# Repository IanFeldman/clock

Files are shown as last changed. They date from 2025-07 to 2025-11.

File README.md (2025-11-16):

# Precision Clock USB Hub with Thermal and Power Sensing

<div align="center">
  PCB Render
</div>

## Features
- Time accurate to the second with ±5ppm drift
- Board temperature monitoring within ±0.5°C
- Dual USB power output up to a combined 1.5A
- Independent USB current/voltage measureement
- On board USB-Serial converter for easy programming/syncing
- Analog display brightness

## Build Deps
- lpc21isp (serial flasher)
- arm-none-eabi-gcc (cortex m compiler)

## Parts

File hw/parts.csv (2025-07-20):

Identifier | Value | Digikey Part Number
U1 |  | 568-10437-5-ND
U2 |  | 768-1135-1-ND
VR1 |  | LM3940IMP-3.3/NOPBCT-ND
S1, S2 |  | 2223-SLW-1678105-6A-N-D-ND
Y1 |  | 535-9887-1-ND
Y2 |  | 50-ECX-.327-CDX-1293CT-ND
U3, U4, U5, U6, U7, U8 |  | 296-14857-1-ND
U9 |  | MCP7940MT-I/SNCT-ND
R12 |  | 2223-PT01-B120D-B102-ND
U13 |  | MCP9808T-E/MSCT-ND
U15, U16 |  | 296-23978-1-ND
U14 |  | AP2192ASG-13DICT-ND
J1, J2, J3 |  | ED2989-ND
SW1, SW2, SW3 |  | EG5353CT-ND
C1, C2 | 16p | 311-4228-1-ND
C10, C6, C7, C13 | 1u | 1276-1029-1-ND
C11, C12 | 47p | 311-1107-1-ND
C3, C4 | 18p | 311-1102-1-ND
C5, C8, C9 | 100u | 490-GRM21BR60G107ME11KCT-ND
D1, D2, D3, D4 |  | 475-LSR976-NR-1CT-ND
R1, R10, R14, R19, R4, R5, R6, R7, R8, R9 | 10k | RR12P10.0KDCT-ND
R11 | 10 | 311-10.0CRCT-ND
R13 | 15k | A126341CT-ND
R15, R16 | 2m | RHM.002AJCT-ND
R17, R18, R20 | 0 | P0.0ACT-ND
R2, R3 | 27 | 311-27.0CRCT-ND
R21 | 15 | RMCF0805FT15R0CT-ND

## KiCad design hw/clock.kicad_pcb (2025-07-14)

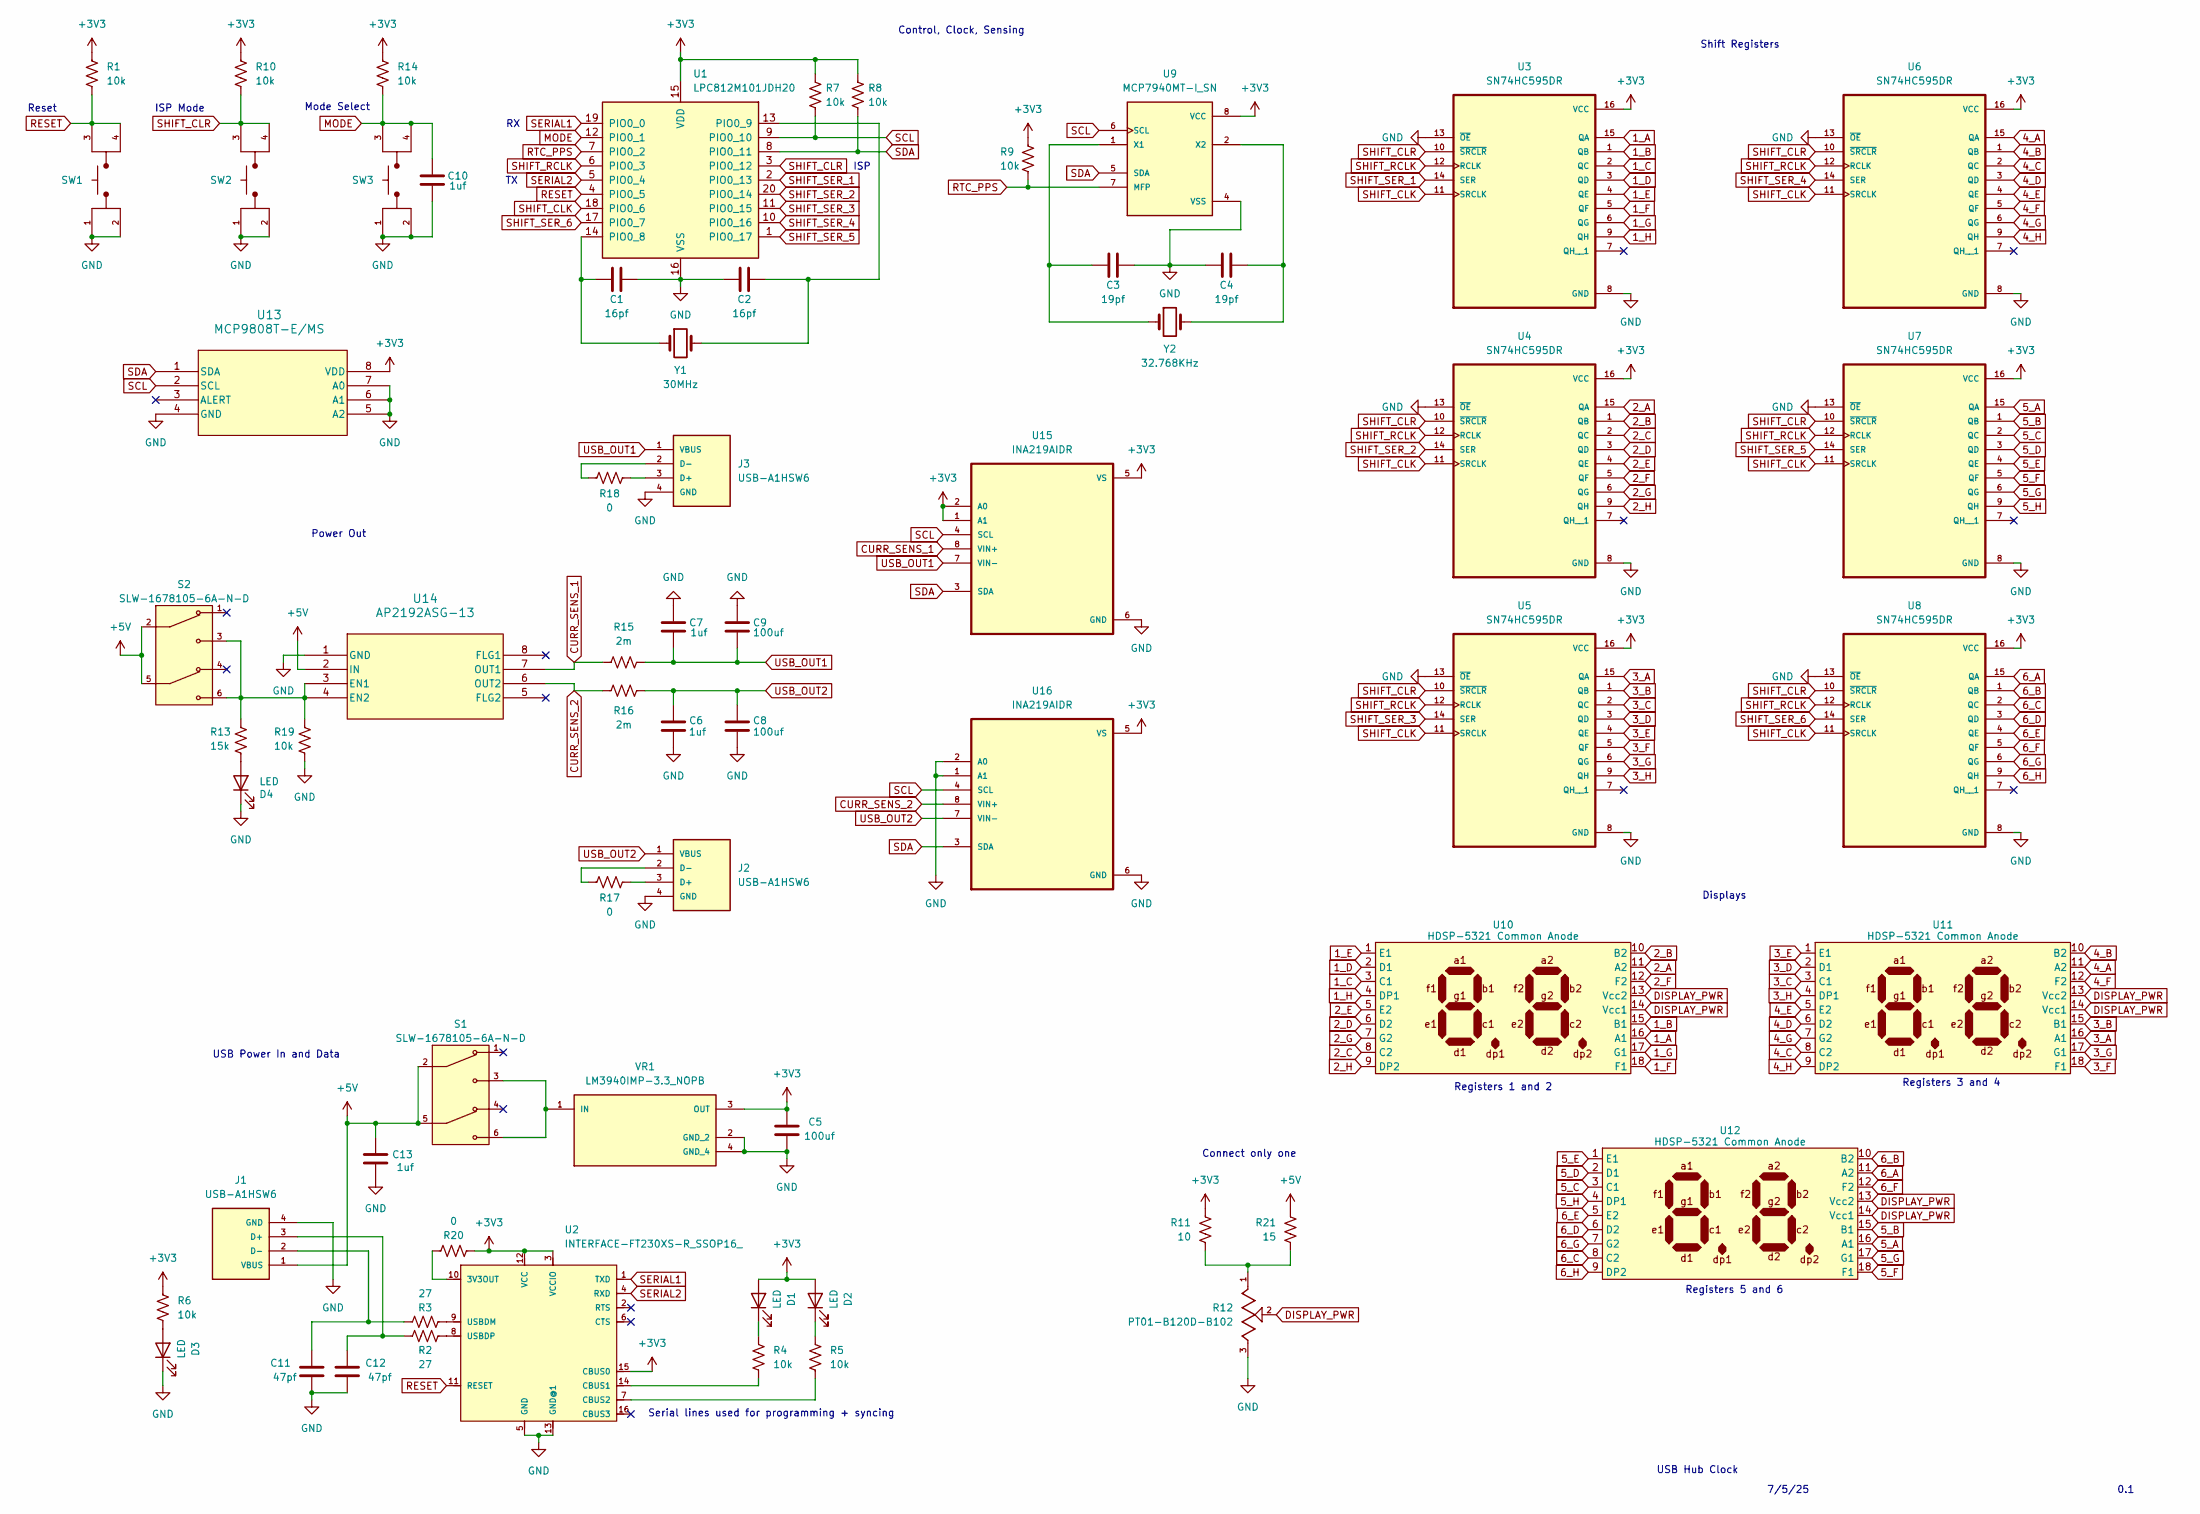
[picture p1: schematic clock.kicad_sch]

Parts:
C1, C2: 16pf; C_0805_2012Metric
C3, C4: 19pf; C_0805_2012Metric
C5, C8, C9: 100uf; C_0805_2012Metric
C6, C7, C10, C13: 1uf; C_0805_2012Metric
C11, C12: 47pf; C_0805_2012Metric
D1, D2, D3, D4: LED; LED_0805_2012Metric
J1, J2, J3: USB-A1HSW6; OST_USB-A1HSW6; PARTREV A
R1, R4, R5, R6, R7, R8, R9, R10, R14, R19: 10k; R_0805_2012Metric
R2, R3: 27; R_0805_2012Metric
R11: 10; R_0805_2012Metric
R12: PT01-B120D-B102; TRIM_PT01-B120D-B102; PARTREV 1.0
R13: 15k; R_0805_2012Metric
R15, R16: 2m; R_0805_2012Metric
R17, R18, R20: 0; R_0805_2012Metric
R21: 15; R_0805_2012Metric
S1, S2: SLW-1678105-6A-N-D; SW_SLW-1678105-6A-N-D; PARTREV 1.01
SW1, SW2, SW3: TL3305AF260QG; SW_TL3305AF260QG; PARTREV C
U1: LPC812M101JDH20; TSSOP-20_4.4x6.5mm_P0.65mm
U2: INTERFACE-FT230XS-R_SSOP16_; SSOP16-0.635-5X4MM; MPN FT230XS-R
U3, U4, U5, U6, U7, U8: SN74HC595DR; SOIC127P600X175-16N
U9: MCP7940MT-I_SN; SOIC127P600X175-8N
U10, U11, U12: HDSP-5321 Common Anode; HDSP-R
U13: MCP9808T-E/MS; MCP9808T
U14: AP2192ASG-13; AP2192ASG_13
U15, U16: INA219AIDR
VR1: LM3940IMP-3.3_NOPB; VREG_LM3940IMP-3.3_NOPB; PARTREV G
Y1: 30MHz; XTAL_ABLS2-30.000MHZ-D4YF-T
Y2: 32.768KHz; XTAL_ECS-.327-12.5-34RR-TR

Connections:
1_A: U3.15 (QA), U10.16 (A1)
1_B: U3.1 (QB), U10.15 (B1)
1_C: U3.2 (QC), U10.3 (C1)
1_D: U3.3 (QD), U10.2 (D1)
1_E: U3.4 (QE), U10.1 (E1)
1_F: U3.5 (QF), U10.18 (F1)
1_G: U3.6 (QG), U10.17 (G1)
1_H: U3.9 (QH), U10.4 (DP1)
2_A: U4.15 (QA), U10.11 (A2)
2_B: U4.1 (QB), U10.10 (B2)
2_C: U4.2 (QC), U10.8 (C2)
2_D: U4.3 (QD), U10.6 (D2)
2_E: U4.4 (QE), U10.5 (E2)
2_F: U4.5 (QF), U10.12 (F2)
2_G: U4.6 (QG), U10.7 (G2)
2_H: U4.9 (QH), U10.9 (DP2)
3_A: U5.15 (QA), U11.16 (A1)
3_B: U5.1 (QB), U11.15 (B1)
3_C: U5.2 (QC), U11.3 (C1)
3_D: U5.3 (QD), U11.2 (D1)
3_E: U5.4 (QE), U11.1 (E1)
3_F: U5.5 (QF), U11.18 (F1)
3_G: U5.6 (QG), U11.17 (G1)
3_H: U5.9 (QH), U11.4 (DP1)
4_A: U6.15 (QA), U11.11 (A2)
4_B: U6.1 (QB), U11.10 (B2)
4_C: U6.2 (QC), U11.8 (C2)
4_D: U6.3 (QD), U11.6 (D2)
4_E: U6.4 (QE), U11.5 (E2)
4_F: U6.5 (QF), U11.12 (F2)
4_G: U6.6 (QG), U11.7 (G2)
4_H: U6.9 (QH), U11.9 (DP2)
5_A: U7.15 (QA), U12.16 (A1)
5_B: U7.1 (QB), U12.15 (B1)
5_C: U7.2 (QC), U12.3 (C1)
5_D: U7.3 (QD), U12.2 (D1)
5_E: U7.4 (QE), U12.1 (E1)
5_F: U7.5 (QF), U12.18 (F1)
5_G: U7.6 (QG), U12.17 (G1)
5_H: U7.9 (QH), U12.4 (DP1)
6_A: U8.15 (QA), U12.11 (A2)
6_B: U8.1 (QB), U12.10 (B2)
6_C: U8.2 (QC), U12.8 (C2)
6_D: U8.3 (QD), U12.6 (D2)
6_E: U8.4 (QE), U12.5 (E2)
6_F: U8.5 (QF), U12.12 (F2)
6_G: U8.6 (QG), U12.7 (G2)
6_H: U8.9 (QH), U12.9 (DP2)
+3V3: C5.2, D1.2 (A), D2.2 (A), R1.2, R6.2, R7.2, R8.2, R9.2, R10.2, R11.2, R14.2, R20.2, U1.15 (VDD), U2.3 (VCCIO), U2.12 (VCC), U2.15 (CBUS0), U3.16 (VCC), U4.16 (VCC), U5.16 (VCC), U6.16 (VCC), U7.16 (VCC), U8.16 (VCC), U9.8 (VCC), U13.8 (VDD), U15.1 (A1), U15.2 (A0), U15.5 (VS), U16.5 (VS), VR1.3 (OUT)
+5V: C13.2, J1.1 (VBUS), R21.2, S1.2, S1.5, S2.2, S2.5, U14.2 (IN)
CURR_SENS_1: R15.2, U14.7 (OUT1), U15.8 (VIN+)
CURR_SENS_2: R16.2, U14.6 (OUT2), U16.8 (VIN+)
DISPLAY_PWR: R12.2, U10.13 (Vcc2), U10.14 (Vcc1), U11.13 (Vcc2), U11.14 (Vcc1), U12.13 (Vcc2), U12.14 (Vcc1)
GND: C1.2, C2.1, C3.2, C4.1, C5.1, C6.1, C7.1, C8.1, C9.1, C10.2, C11.1, C12.1, C13.1, D3.1 (K), D4.1 (K), J1.4 (GND), J2.4 (GND), J3.4 (GND), R12.3, R19.1, SW1.1, SW1.2, SW2.1, SW2.2, SW3.1, SW3.2, U1.16 (VSS), U2.5 (GND), U2.13 (GND@1), U3.8 (GND), U3.13 (~OE), U4.8 (GND), U4.13 (~OE), U5.8 (GND), U5.13 (~OE), U6.8 (GND), U6.13 (~OE), U7.8 (GND), U7.13 (~OE), U8.8 (GND), U8.13 (~OE), U9.4 (VSS), U13.4 (GND), U13.5 (A2), U13.6 (A1), U13.7 (A0), U14.1 (GND), U15.6 (GND), U16.1 (A1), U16.2 (A0), U16.6 (GND), VR1.2 (GND_2), VR1.4 (GND_4)
MODE: C10.1, R14.1, SW3.3, SW3.4, U1.12 (PIO0_1)
unnamed: D1.1 (K), R4.2
unnamed: D2.1 (K), R5.2
unnamed: D3.2 (A), R6.1
unnamed: D4.2 (A), R13.1
unnamed: C12.2, J1.3 (D+), R2.1
unnamed: C11.2, J1.2 (D-), R3.2
unnamed: J2.3 (D+), R17.1
unnamed: J2.2 (D-), R17.2
unnamed: J3.3 (D+), R18.1
unnamed: J3.2 (D-), R18.2
unnamed: R11.1, R12.1, R21.1
unnamed: C1.1, U1.14 (PIO0_8), Y1.1
unnamed: C2.2, U1.13 (PIO0_9), Y1.2
unnamed: R20.1, U2.10 (3V3OUT)
unnamed: R4.1, U2.14 (CBUS1)
unnamed: R5.1, U2.7 (CBUS2)
unnamed: R3.1, U2.9 (USBDM)
unnamed: R2.2, U2.8 (USBDP)
unnamed: C3.1, U9.1 (X1), Y2.1
unnamed: C4.2, U9.2 (X2), Y2.2
unnamed: R13.2, R19.2, S2.3, S2.6, U14.3 (EN1), U14.4 (EN2)
unnamed: S1.3, S1.6, VR1.1 (IN)
RESET: R1.1, SW1.3, SW1.4, U1.4 (PIO0_5), U2.11 (RESET)
RTC_PPS: R9.1, U1.7 (PIO0_2), U9.7 (MFP)
SCL: R7.1, U1.9 (PIO0_10), U9.6 (SCL), U13.2 (SCL), U15.4 (SCL), U16.4 (SCL)
SDA: R8.1, U1.8 (PIO0_11), U9.5 (SDA), U13.1 (SDA), U15.3 (SDA), U16.3 (SDA)
SERIAL1: U1.19 (PIO0_0), U2.1 (TXD)
SERIAL2: U1.5 (PIO0_4), U2.4 (RXD)
SHIFT_CLK: U1.18 (PIO0_6), U3.11 (SRCLK), U4.11 (SRCLK), U5.11 (SRCLK), U6.11 (SRCLK), U7.11 (SRCLK), U8.11 (SRCLK)
SHIFT_CLR: R10.1, SW2.3, SW2.4, U1.3 (PIO0_12), U3.10 (~SRCLR), U4.10 (~SRCLR), U5.10 (~SRCLR), U6.10 (~SRCLR), U7.10 (~SRCLR), U8.10 (~SRCLR)
SHIFT_RCLK: U1.6 (PIO0_3), U3.12 (RCLK), U4.12 (RCLK), U5.12 (RCLK), U6.12 (RCLK), U7.12 (RCLK), U8.12 (RCLK)
SHIFT_SER_1: U1.2 (PIO0_13), U3.14 (SER)
SHIFT_SER_2: U1.20 (PIO0_14), U4.14 (SER)
SHIFT_SER_3: U1.11 (PIO0_15), U5.14 (SER)
SHIFT_SER_4: U1.10 (PIO0_16), U6.14 (SER)
SHIFT_SER_5: U1.1 (PIO0_17), U7.14 (SER)
SHIFT_SER_6: U1.17 (PIO0_7), U8.14 (SER)
USB_OUT1: C7.2, C9.2, J3.1 (VBUS), R15.1, U15.7 (VIN-)
USB_OUT2: C6.2, C8.2, J2.1 (VBUS), R16.1, U16.7 (VIN-)

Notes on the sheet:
Power Out
Registers 1 and 2
7/5/25
ISP Mode
Mode Select
USB Power In and Data
Reset
USB Hub Clock
Connect only one
Registers 3 and 4
Displays
ISP
Serial lines used for programming + syncing
0.1
Control, Clock, Sensing
Shift Registers
Registers 5 and 6

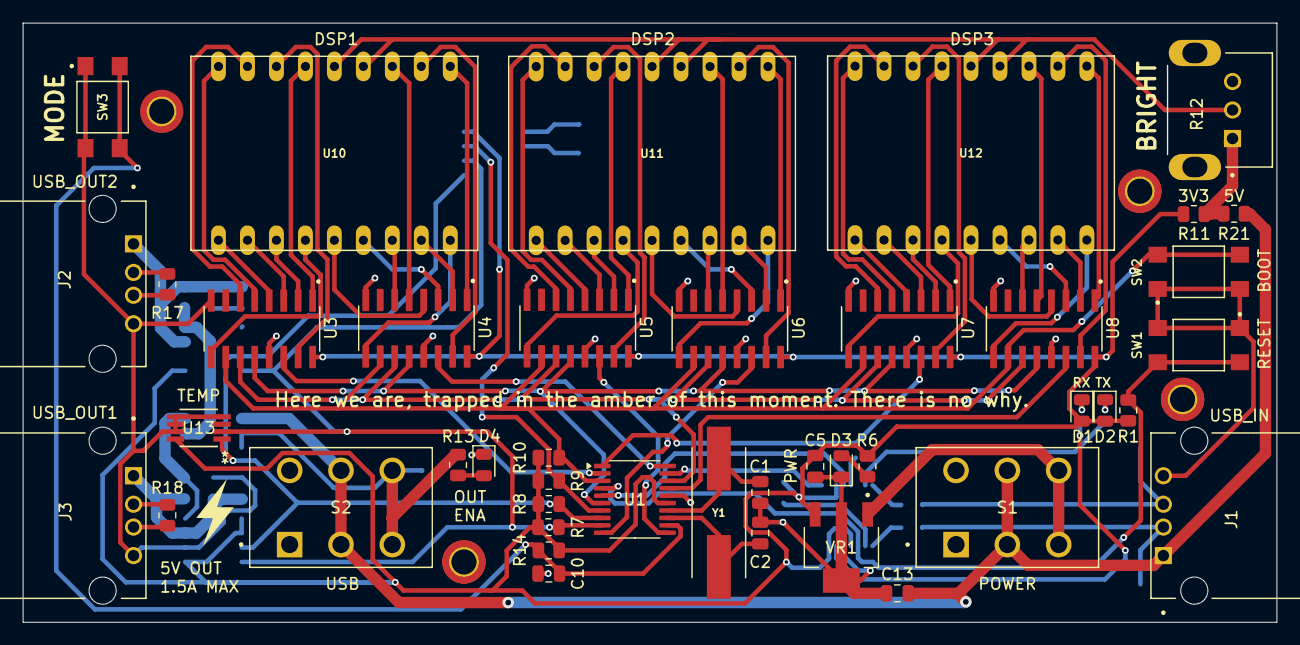
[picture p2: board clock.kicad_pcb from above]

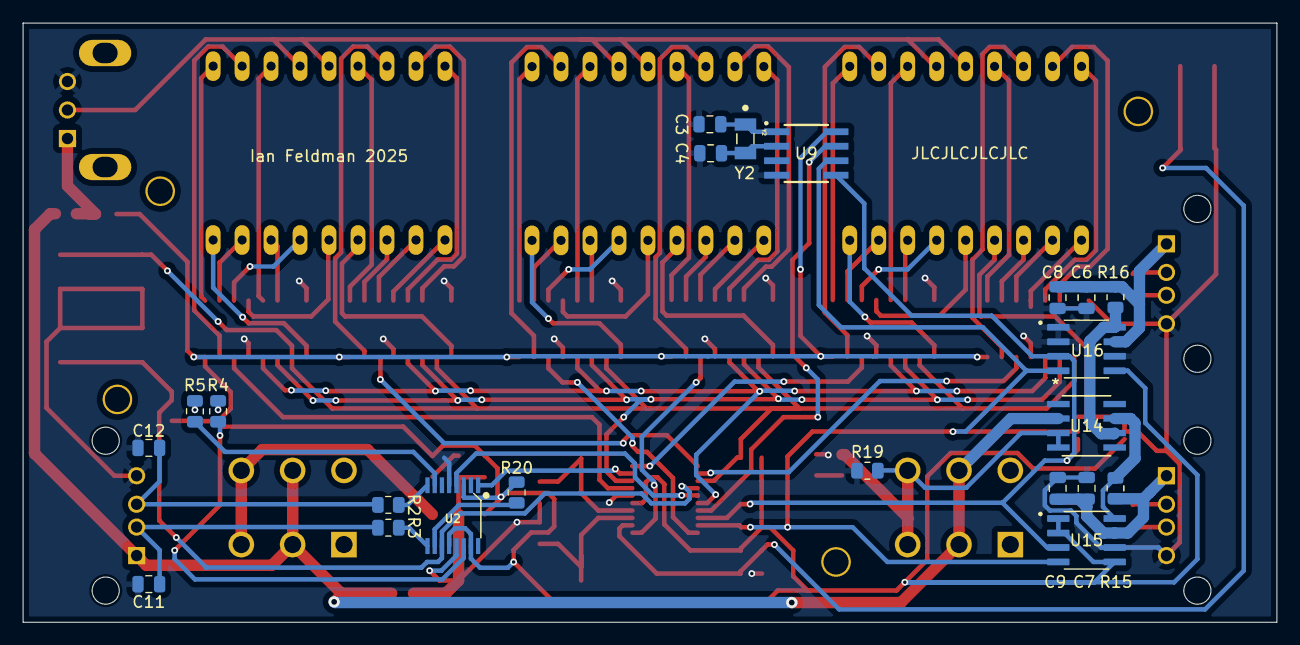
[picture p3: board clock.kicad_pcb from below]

Board: 2 copper layers, 109.9 x 52.5 mm, 65 parts (22 on the bottom side), 94 nets.

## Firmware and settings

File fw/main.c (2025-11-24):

#include "LPC8xx.h"
#include "display.h"
#include "i2c.h"
#include "uart.h"
#include "main.h"

static inline void increment_time(void);
static void gpio_int_initialize(void);
static int debounce(void);

/* isr variables */
volatile rtc_time_t time = { 0, 0, 0, 0, 0 };
volatile int pps_flag = 0;
volatile int mode_flag = 0;
volatile int rx_flag = 0;
volatile char rx_buffer[32];

int main(void)
{
    display_initialize();
    uart_initialize();
    i2c_initialize();

    /* reset terminal */
    uart_print_esc(CLEAR_SCREEN);
    uart_print_esc(HOME_CURSOR);

    /* initialize pin interrupts */
    gpio_int_initialize();

    /* initalize time */
    i2c_rtc_output_config();
    i2c_rtc_set_time(time);

    /* 0: off, 1: time, ... */
    int mode = 1;
    int update_display = 0;

    while (1)
    {
        /* check incoming message */
        if (rx_flag)
        {
            uart_handle_message((char *)rx_buffer, (rtc_time_t *)&time);
            i2c_rtc_set_time(time);
            update_display = 1;
            rx_flag = 0;
        }

        /* check mode */
        if (mode_flag && debounce())
        {
            mode++;
            if (mode >= MODE_COUNT)
            {
                mode = 0;
                display_clear();
            }
            else
            {
                update_display = 1;
            }
        }

        /* service 1hz pps */
        if (pps_flag || update_display)
        {
            switch(mode)
            {
                /* normal time display */
                case 1:
                    display_time((rtc_time_t *)&time);
                    break;

                /* temperature display */
                case 2:
                    tmp_temp_t temp_c = i2c_tmp_get_temp(DEG_C);
                    display_temp(&temp_c);
                    break;

                /* temperature display */
                case 3:
                    tmp_temp_t temp_f = i2c_tmp_get_temp(DEG_F);
                    display_temp(&temp_f);
                    break;

                /* off */
                default:
                    break;
            }
            pps_flag = 0;
            update_display = 0;
        }
    }

    return 1;
}


/* Enable external interrupts for gpio pins:
 *  - Rising edge PININT0 for PPS (PIO0_2)
 *  - Falling edge PININT1 for MODE (PIO0_1)
 */
static void gpio_int_initialize(void)
{
    /* disable SWDIO function (bit 3) so PIO0_2 can be used as GPIO */
    /* disable ACMP_I2 function (bit 1) so PIO0_1 can be used as GPIO */
    LPC_SWM->PINENABLE0 |= (1 << 3) | (1 << 1);
    /* set pins as inputs */
    LPC_GPIO_PORT->DIR0 &= ~((1 << PPS_PIN) | (1 << MODE_PIN));
    /* set external interrupts */
    LPC_SYSCON->PINTSEL[PPS_IRQ] = PPS_PIN;
    LPC_SYSCON->PINTSEL[MODE_IRQ] = MODE_PIN;
    /* set edge sensitive */
    LPC_PIN_INT->ISEL &= ~((1 << PPS_IRQ) | (1 << MODE_IRQ));
    /* PPS detect rising edge */
    LPC_PIN_INT->IENR |= (1 << PPS_IRQ);
    /* MODE detect falling edge */
    LPC_PIN_INT->IENF |= (1 << MODE_IRQ);
    /* clear any pending/leftover flags */
    LPC_PIN_INT->IST = 0xFF;
    /* enable interrupts */
    NVIC_EnableIRQ(PININT0_IRQn);
    NVIC_EnableIRQ(PININT1_IRQn);
}


/* Increment current time by one second */
static inline void increment_time(void)
{
    time.seconds_ones++;
    /* check seconds */
    if (time.seconds_ones > 9)
    {
        time.seconds_ones = 0;
        time.seconds_tens++;

        if (time.seconds_tens > 5)
        {
            time.seconds_tens = 0;
            time.minutes_ones++;
        }
    }

    /* check minutes */
    if (time.minutes_ones > 9)
    {
        time.minutes_ones = 0;
        time.minutes_tens++;

        if (time.minutes_tens > 5)
        {
            time.minutes_tens = 0;
            time.hours_ones++;
        }
    }

    /* check hours */
    if (time.hours_ones > 9)
    {
        time.hours_ones = 0;
        time.hours_tens++;
    }

    /* reset hours to 0 at 24 */
    if (time.hours_tens > 1 && time.hours_ones > 3)
    {
        time.hours_tens = 0;
        time.hours_ones = 0;
    }
}


/* Debounce MODE pin input. Return 1 if pressed, 0 otherwise */
static int debounce(void)
{
    static int counter = 0;

    counter++;
    /* timeout */
    if (counter > MODE_DEBOUNCE)
    {
        /* active low */
        int press = !(LPC_GPIO_PORT->B0[MODE_PIN]);
        counter = 0; 
        mode_flag = 0;
        return press;
    }
    return 0;
}


/* RTC PPS external interrrupt handler */
void PININT0_IRQHandler(void)
{
    /* check interrupt flag */
    if (LPC_PIN_INT->IST & (1 << PPS_IRQ))
    {
        pps_flag = 1;
        increment_time();
        LPC_PIN_INT->IST = (1 << PPS_IRQ);
    }
}


/* MODE pin external interrrupt handler */
void PININT1_IRQHandler(void)
{
    /* check interrupt flag and set mode flag */
    if (LPC_PIN_INT->IST & (1 << MODE_IRQ))
    {
        mode_flag = 1;
        LPC_PIN_INT->IST = (1 << MODE_IRQ);
    }
}


/* Serial interrupt handler */
void UART0_IRQHandler(void)
{
    static int rx_idx = 0;

    /* rx ready */
    if (LPC_USART0->INTSTAT & (1 << UART_RX_INT_RDY)) {
        /* get byte */
        char rx_byte = LPC_USART0->RXDATA;
        if (!rx_idx && (rx_byte != UART_RX_SYNC)) return;
        rx_buffer[rx_idx++] = rx_byte;

        /* reset index and set flag if we received full message */
        int full_msg_size = (sizeof(clk_set_msg_t) + sizeof(UART_RX_SYNC));
        if (rx_idx == full_msg_size) {
            rx_idx = 0;
            rx_flag = 1;
        }
    }
}

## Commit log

2025-06-09 Create hardware files
    [clock.kicad_pcb, clock.kicad_sch]
2025-06-09 Add USB
    [clock.kicad_sch]
2025-06-12 Add voltage reg and serial converter
    [clock.kicad_sch]
2025-06-12 Change mcu
    [clock.kicad_sch]
2025-06-17 Shift registers
    [clock.kicad_sch]
2025-06-20 Variable brightness, temperature sense
    [clock.kicad_sch]
2025-06-21 USB output
    [clock.kicad_sch]
2025-06-24 Assign footprints
    [clock.kicad_pcb, clock.kicad_sch]
2025-06-30 Minor schematic changes, routing
    [clock.kicad_pcb, clock.kicad_sch]
2025-07-03 Place components
    [clock.kicad_pcb]
2025-07-03 Route top
    [clock.kicad_pcb]
2025-07-05 Routing and minor schematic changes
    [clock.kicad_pcb, clock.kicad_sch]
2025-07-06 Update hw
    [clock.kicad_pcb, clock.kicad_sch]
2025-07-06 Final touches
    [clock.kicad_pcb, clock.kicad_sch]
2025-07-06 Move temp sensor, add quote
    [clock.kicad_pcb]
2025-07-06 Add pull load switch pull down
    [clock.kicad_pcb, clock.kicad_sch]
2025-07-06 Add safety resistors and 5v display backup supply
    [clock.kicad_pcb, clock.kicad_sch]
2025-07-06 Flip designator
    [clock.kicad_pcb]
2025-07-06 Increase usb out trace widths
    [clock.kicad_pcb]
2025-07-14 Change passives
    [clock.kicad_pcb, clock.kicad_sch]
2025-07-20 Add parts list
    [parts.csv]
2025-07-26 Attempt to fix boilerplate
    [main.c, startup_lpc812.c]
2025-08-05 Add i2c
2025-09-02 Add i2c write
2025-09-02 Add i2c read
2025-09-03 Start uart support
2025-11-16 Update i2c
2025-11-18 Interrupts working
2025-11-21 Support mode button
